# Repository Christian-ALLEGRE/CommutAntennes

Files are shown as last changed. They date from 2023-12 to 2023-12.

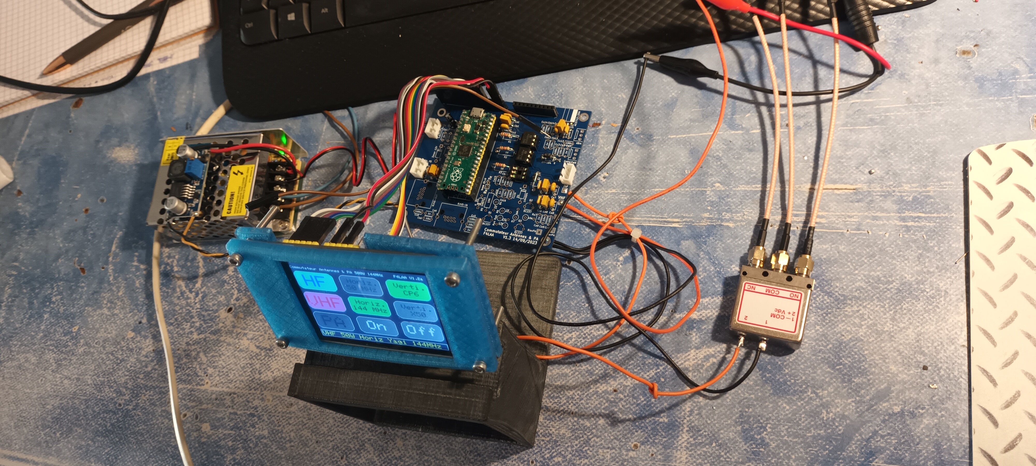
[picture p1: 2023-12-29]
images/20230930_181311.jpg

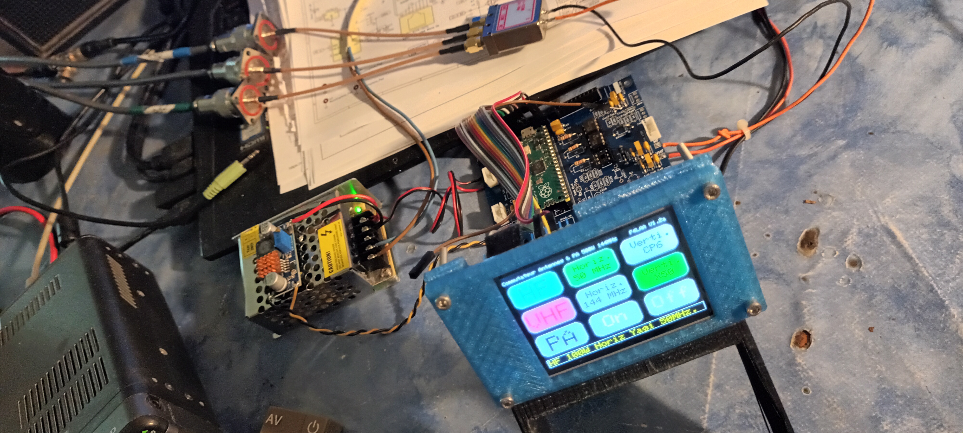
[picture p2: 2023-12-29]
images/20230930_235537.jpg

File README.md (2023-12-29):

# CommutAntennes
Antennas switcher using RPIPico and TFT 2"8 TouchScreen

V1.2 : 
  - The TFT 2"8 TouchScreen uses parallel 8 bits communication with RpiPico
  - PCB was manufactured by JLCPcb using Kicad/Ampli144MHz.zip (2023/09/14)
  - RpiPico Program V1.2 UI was design to manage :
    - The antenna switcher : 2 coax relay (HF and VHF)
    - A futur 144MHz 500W Power amplifier (not yet build at this time)
  
Updated on 29/12/2023 : 
  - The source code is now compatible with PlatformIO
    - CommutAntenneRpiPico-V1.2a.ino becomes src/main.cpp
    - The requested libraries were put in lib directory
    - a few lines where commented in GFX_Library_for_Arduino and TouchScreenOnRpPico
      to allow those libraries to compile (search for// F4LAA comment to find them)

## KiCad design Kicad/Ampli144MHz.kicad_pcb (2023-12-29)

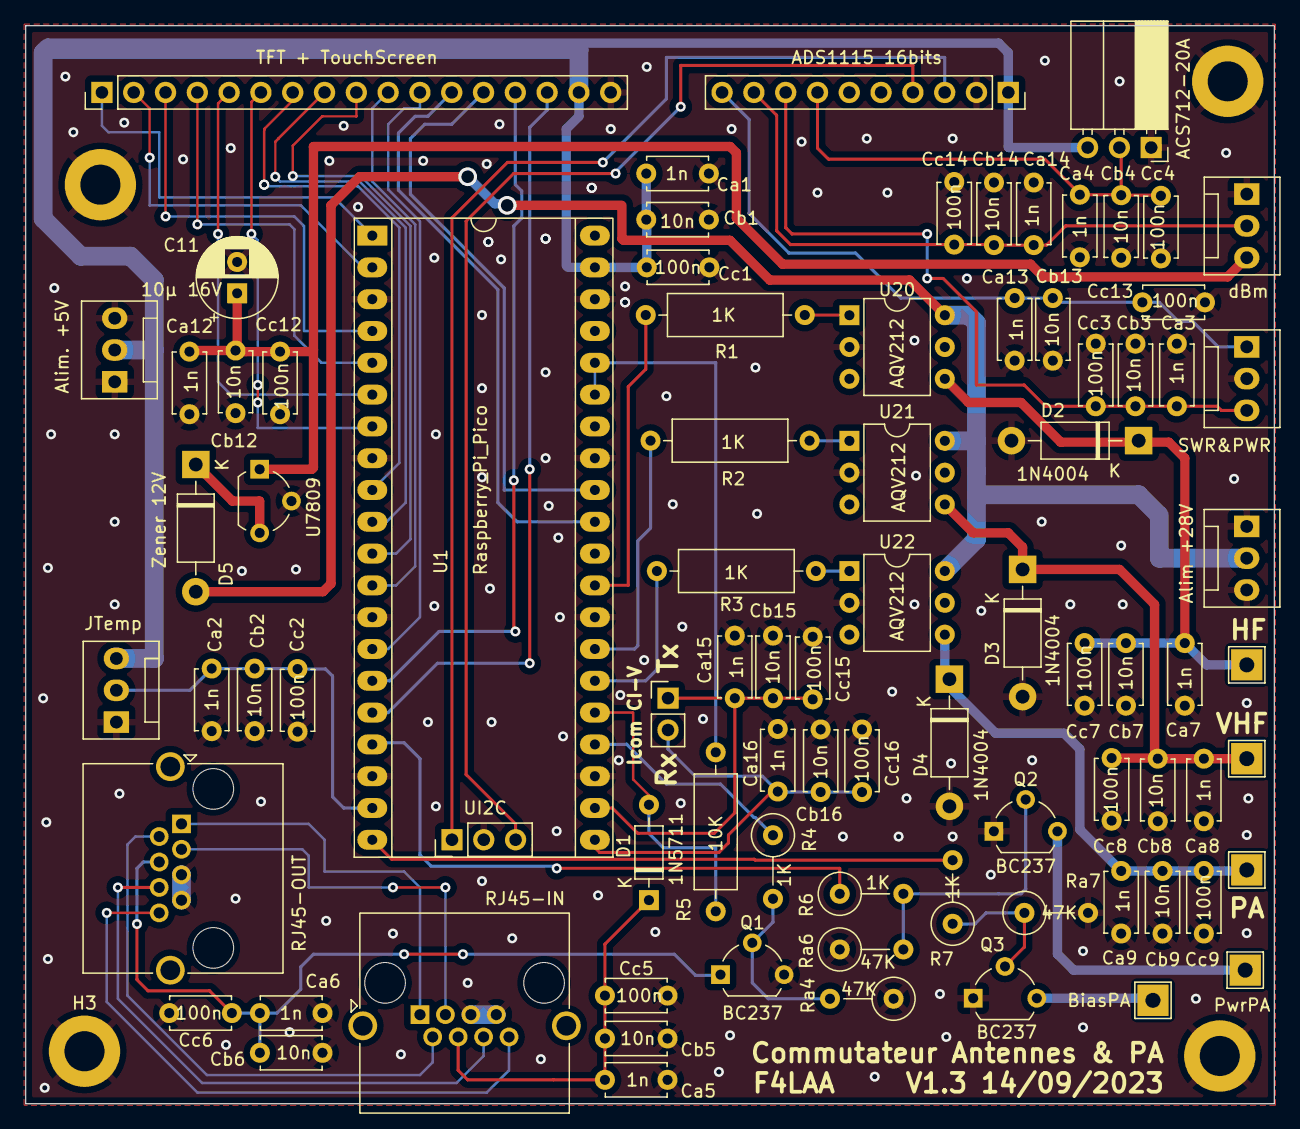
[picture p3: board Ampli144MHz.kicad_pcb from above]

Board: 2 copper layers, 99.7 x 86.1 mm, 87 parts (0 on the bottom side), 37 nets.

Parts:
Alim +28V: Alim28V; FanPinHeader_1x03_P2.54mm_Vertical
C11: 10µ 16V; CP_Radial_D6.3mm_P2.50mm
CK1: RELAY_K1; TestPoint_THTPad_2.5x2.5mm_Drill1.2mm
CK2: RELAY_K2; TestPoint_THTPad_2.5x2.5mm_Drill1.2mm
CK3: RELAY_K3; TestPoint_THTPad_2.5x2.5mm_Drill1.2mm
CK220V: Alim 48V PA; TestPoint_THTPad_2.5x2.5mm_Drill1.2mm
CKBias1: BiasPA; TestPoint_THTPad_2.5x2.5mm_Drill1.2mm
Ca1, Ca2, Ca3, Ca4, Ca5, Ca6, Ca7, Ca8, Ca9, Ca12, Ca13, Ca14, Ca15, Ca16: 1n; C_Disc_D4.7mm_W2.5mm_P5.00mm
Cb1, Cb2, Cb3, Cb4, Cb5, Cb6, Cb7, Cb8, Cb9, Cb12, Cb13, Cb14, Cb15, Cb16: 10n; C_Disc_D4.7mm_W2.5mm_P5.00mm
Cc1, Cc2, Cc3, Cc4, Cc5, Cc6, Cc7, Cc8, Cc9, Cc12, Cc13, Cc14, Cc15, Cc16: 100n; C_Disc_D4.7mm_W2.5mm_P5.00mm
D1: 1N5711; D_DO-35_SOD27_P7.62mm_Horizontal
D2, D3, D4: 1N4004; D_DO-41_SOD81_P10.16mm_Horizontal
D5: Zener 12V; D_DO-41_SOD81_P10.16mm_Horizontal
H1, H2, H3, H4: MountingHole_Pad; MountingHole_3.2mm_M3_ISO7380_Pad
J5: Alim. +5V; FanPinHeader_1x03_P2.54mm_Vertical
JADC16bits: ADS1115 16bits; PinSocket_1x10_P2.54mm_Vertical
JAmp: ACS712-20A; PinSocket_1x03_P2.54mm_Horizontal
JCIV1: Icom CI-V; PinHeader_1x02_P2.54mm_Vertical
JS+P: SWR&PWR; FanPinHeader_1x03_P2.54mm_Vertical
JTFT+Touch: TFT + TouchScreen; PinHeader_1x17_P2.54mm_Vertical
JTemp: Temp; FanPinHeader_1x03_P2.54mm_Vertical
JdBm: dBm; FanPinHeader_1x03_P2.54mm_Vertical
Q1, Q2, Q3: BC237; TO-92L_Wide
R1, R2, R3: 1K; R_Axial_DIN0309_L9.0mm_D3.2mm_P12.70mm_Horizontal
R4, R6, R7: 1K; R_Axial_DIN0309_L9.0mm_D3.2mm_P5.08mm_Vertical
R5: 10K; R_Axial_DIN0309_L9.0mm_D3.2mm_P12.70mm_Horizontal
RJ45-IN, RJ45-OUT: RJ45_Amphenol_RJHSE5380
Ra4, Ra6, Ra7: 47K; R_Axial_DIN0309_L9.0mm_D3.2mm_P5.08mm_Vertical
U1: Raspberry_Pi_Pico; DIP-40_0.700in_Socket_LongPads
U20, U21, U22: AQV212; DIP-6_W7.62mm
U7809: LM78L09; TO-92L_Wide
UI2C: I2C; PinHeader_1x03_P2.54mm_Vertical

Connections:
+3.3V: R5.2, U1.35, U1.36
+5V: Ca1.2, Cb1.1, Cc1.2, J5.2, JADC16bits.1, JAmp.3, JTFT+Touch.16, JTemp.3, U1.39
+9V: C11.1, Ca12.1, Cb12.1, Cc12.1, JdBm.3, U7809.1 (VO)
+16V: D5.1 (K), U7809.3 (VI)
+28V: Alim +28V.2, U20.6, U21.6, U22.6
ADC0: JTFT+Touch.12, U1.31
ADC1: JTFT+Touch.13, U1.32
Amp: Ca4.1, Cb4.1, Cc4.1, JADC16bits.7, JAmp.2
BiasPAOff: R7.2, U1.20
CBiasPA: CKBias1.1, Q3.3 (E)
CK1: CK1.1, Ca7.1, Cb7.2, Cc7.2, D2.1 (K), U20.4
CK2: CK2.1, Ca8.1, Cb8.1, Cc8.2, D3.1 (K), U21.4
CK3: CK3.1, Ca9.2, Cb9.2, Cc9.2, D4.1 (K), U22.4
CK220V: CK220V.1, Q2.3 (E)
CPAOnOff: R6.1, U1.17
CPTTOut: Q1.2 (B), R4.1, R4.2, U1.24
GND: Alim +28V.1, Alim +28V.3, C11.2, Ca1.1, Ca2.2, Ca3.2, Ca4.2, Ca5.2, Ca6.2, Ca7.2, Ca8.2, Ca9.1, Ca12.2, Ca13.1, Ca14.2, Ca15.2, Ca16.2, Cb1.2, Cb2.1, Cb3.2, Cb4.2, Cb5.2, Cb6.2, Cb7.1, Cb8.2, Cb9.1, Cb12.2, Cb13.1, Cb14.2, Cb15.2, Cb16.2, Cc1.1, Cc2.1, Cc3.2, Cc4.2, Cc5.2, Cc6.2, Cc7.1, Cc8.1, Cc9.1, Cc12.2, Cc13.2, Cc14.2, Cc15.2, Cc16.2, D2.2 (A), D3.2 (A), D4.2 (A), H1.1, H2.1, H3.1, H4.1, J5.1, J5.3, JADC16bits.2, JAmp.1, JS+P.2, JTFT+Touch.17, JTemp.1, JdBm.1, Q1.3 (E), Q2.1 (C), Q3.1 (C), RJ45-IN.5, RJ45-IN.7, RJ45-OUT.5, RJ45-OUT.7, Ra4.1, Ra6.1, Ra7.2, U1.3, U1.8, U1.13, U1.18, U1.23, U1.28, U1.33, U1.38, U20.2, U21.2, U22.2, U7809.2 (GND), UI2C.2
unnamed: D1.2 (A), R5.1
unnamed: Q2.2 (B), R6.2, Ra6.2
unnamed: R1.1, U1.29
unnamed: R1.2, U20.1
unnamed: R2.1, U1.27
unnamed: R2.2, U21.1
unnamed: R3.1, U1.26
unnamed: R3.2, U22.1
PTT In: Ca5.1, Cb5.1, Cc5.1, D1.1 (K), RJ45-IN.4, U1.25
PTTOut: Ca6.1, Cb6.1, Cc6.1, Q1.1 (C), RJ45-OUT.4
PWR: Ca13.2, Cb13.2, Cc13.1, JADC16bits.10, JS+P.1
RX: Ca16.1, Cb16.1, Cc16.1, JCIV1.2, U1.21
SCL: JADC16bits.3, UI2C.1
SDA: JADC16bits.4, UI2C.3
SWR: Ca3.1, Cb3.1, Cc3.1, JADC16bits.8, JS+P.3
TX: Ca15.1, Cb15.1, Cc15.1, JCIV1.1, U1.22
T°: Ca2.1, Cb2.2, Cc2.2, JTemp.2, U1.19
XP: JTFT+Touch.14, U1.15
YM: JTFT+Touch.15, U1.16
dBm: Ca14.1, Cb14.1, Cc14.1, JADC16bits.9, JdBm.2

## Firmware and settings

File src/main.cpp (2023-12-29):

// CommutAntenneRpiPico.ino
#define VERSION "V1.2a"
//
// Programme : Commutateur d'Antennes + PA VHF 500W
// Conçu par : F4LAA 
// Version   : V2.0 (15/09/2023)
//
// Programme inspiré de : 
//   Contrôleur de commutateur Coaxial 8:1 Ameritron (ou similaire), Version 1.
//   Utilise un Raspberry Pi Pico. Développé sous Arduino IDE.
//   Électro-Bidouilleur, Juin 2023. https://www.youtube.com/Électro-Bidouilleur
//   Licence de droits: Attribution 4.0 International (CC BY 4.0)  Lisez https://creativecommons.org/licenses/by/4.0/deed.fr
//
// =========================================================================================================================
// V1.0 (14/09/2023)
//
// TFTArduino : Ecran Elegoo 320 x 240 couleur + TouchScreen
//   Programme Arduino gérant l'affichage LCD du commutateur (boutons Commut H/V en HF et VHF, PA Enable/Disable, PA On/Off)
//   Dérivé du programme exemple Elegoo, il se trouve sur ACSOFTDVLP 
//   dans E:\ACSoft\DVLP\arduino-0022\ACSoft\Afficheurs\TFT\TFTArduino
//   Utilise une version modifiée de la librairie EleGoo_GFX (.cpp, .h) 
//     fonctions containsV() et containsH() (au lieu de contains() dans la librairie d'origine)
//
// =========================================================================================================================
// V2.0 (14/09/2023)
//
// Portage Arduino vers Raspeberry Pico
//   CommutAntenneRpiPico.ino
//   ==> Ce programme est la version Rpi Pico
//
// RpiPico+TFT Elegoo et Librairie GFX Library for Arduino V1.3.7 par "Moon On Our Nation...""
// https://github.com/moononournation/Arduino_GFX
// Trouvé par : https://www.instructables.com/ArduinoGFX/
//
// Adaptation F4LAA : 
//    Arduino_RPiPicoPAR8.h, .c :
//     Ajout de la méthode int32_t Arduino_RPiPicoPAR8::digitalPinToBitMask(int32_t pin) 
//     #define digitalPinToBitMask(pin)    (1UL << (pin))
//
//   Adaptation Arduino_GFX.h, .c :
//     Ajout classe Arduino_GFX_Button (repris de Elegoo_GFX_Button)
//
//   Adaptation Arduino_GFX_Library.h :
//     Mise en comentaire des databus/xxxx inutilisés 
//       Arduino_HWSPI, Arduino_RPiPicoPAR16, Arduino_RPiPicoSPI,  
//
// La define TARGET_RP2040 est active à la compilatiopn sur RpiPico.
// 
// =========================================================================================================================
//#include <EEPROM.h>

// Based on ELEGOO TouhScreen
#include <TouchScreenOnRpiPico.h> // by F4LAA

#define XP 0   // GPIO0 (Sur Arduino, c'était 8 = D0) can be a digital pin
#define YM 1   // GPIO1 (Sur Arduino, c'était 9 = D1) can be a digital pin
#define YP 26  // GPIO26 = ADC0 (Sur Arduino, c'était A3)  // must be an analog pin, use "An" notation!
#define XM 27  // GPIO27 = ADC1 (Sur Arduino, c'était A2)  // must be an analog pin, use "An" notation!

TouchScreen ts = TouchScreen(XP, YP, XM, YM, 300);
#define MINPRESSURE 75
#define MAXPRESSURE 300

// Touch For New ILI9341 TP / ADC RpiPico
// ATTENTION X, Y Ecran = Y, X TouchPad (à cause de la rotation de 270° non prise en compte par le TP)
//
// Pour le Y de l'écran (qui utilise le X du touchPad)
#define TS_MINX 786
#define TS_MAXX 3426

// Pour le X de l'écran (qui utilise le Y du touchPad)
#define TS_MINY 587 
#define TS_MAXY 3413

int xmin = 32000;
int xmax = 0;
int ymin = 32000;
int ymax = 0;

// TFT LCD connecté en // 8 bits (D0 ... D7 sur GPIO0 ... GPIO7)
// https://www.instructables.com/ArduinoGFX/
#include <Arduino_GFX_Library.h>

// Voici les connexions sur un Rasprerry Pi Pico. Les numéros indiqués correspondent aux appellations GPxx du brochage.
#define LCD_RD 8 // GPIO8 (Sur Arduino, c'était A1) // LCD Write goes to Analog 1
#define LCD_WR 9 // GPIO9 (Sur Arduino, c'était A0) // LCD Read goes to Analog 0
#define LCD_RESET 10 // GPIO10 (Sur Arduino, c'était A4) // Can alternately just connect to Arduino's reset pin
#define LCD_CS 26 // GPIO26_ADC0 (Sur Arduino, c'était A3, Must be Analog) // Chip Select goes to Analog 3
#define LCD_CD 27 // GPIO27_ADC1 (Sur Arduino, c'était A2 // Command/Data goes to Analog 2

//Elegoo_TFTLCD tft(LCD_CS, LCD_CD, LCD_WR, LCD_RD, LCD_RESET);
// Replaced by :
// Display D0-D7 connect to GPIO 0-7.
Arduino_DataBus *bus = new Arduino_RPiPicoPAR8(LCD_CD, LCD_CS, LCD_WR, LCD_RD); 
// More data bus class: https://github.com/moononournation/Arduino_GFX/wiki/Data-Bus-Class 

Arduino_GFX *tft = new Arduino_ILI9341(bus, LCD_RESET, 0 , false );
// More display class: https://github.com/moononournation/Arduino_GFX/wiki/Display-Class

// Color definitions
#define ILI9341_BLACK       0x0000      /*   0,   0,   0 */
#define ILI9341_NAVY        0x000F      /*   0,   0, 128 */
#define ILI9341_DARKGREEN   0x03E0      /*   0, 128,   0 */
#define ILI9341_DARKCYAN    0x03EF      /*   0, 128, 128 */
#define ILI9341_MAROON      0x7800      /* 128,   0,   0 */
#define ILI9341_PURPLE      0x780F      /* 128,   0, 128 */
#define ILI9341_OLIVE       0x7BE0      /* 128, 128,   0 */
#define ILI9341_LIGHTGREY   0xC618      /* 192, 192, 192 */
#define ILI9341_DARKGREY    0x7BEF      /* 128, 128, 128 */
#define ILI9341_BLUE        0x001F      /*   0,   0, 255 */
#define ILI9341_GREEN       0x07E0      /*   0, 255,   0 */
#define ILI9341_CYAN        0x07FF      /*   0, 255, 255 */
#define ILI9341_RED         0xF800      /* 255,   0,   0 */
#define ILI9341_MAGENTA     0xF81F      /* 255,   0, 255 */
#define ILI9341_YELLOW      0xFFE0      /* 255, 255,   0 */
#define ILI9341_WHITE       0xFFFF      /* 255, 255, 255 */
#define ILI9341_ORANGE      0xFD20      /* 255, 165,   0 */
#define ILI9341_GREENYELLOW 0xAFE5      /* 173, 255,  47 */
#define ILI9341_PINK        0xF81F

/******************* UI details */
#define BUTTON_X 48
#define BUTTON_Y 52
#define BUTTON_W 95 // 60
#define BUTTON_H 55 // 30
#define BUTTON_SPACING_X 15 // 20
#define BUTTON_SPACING_Y 10
#define BUTTON_TEXTSIZE 3

// We have a setHeader line for like, is FONA working
#define posHeader_X 0
#define posHeader_Y 10

// text box where numbers go
#define TEXT_X 1
#define TEXT_Y 218 // 10
#define TEXT_W 318 // 220
#define TEXT_H 20
#define TEXT_TSIZE 2
#define TEXT_TCOLOR ILI9341_YELLOW

#define RelaiAlimPA 11  // GPIO11
#define DTemp 14        // GPIO14
#define PttOut 18       // GPIO18
#define PttIn 19        // GPIO19
#define RelaiPA 20      // GPIO20
#define RelaiVHF 21     // GPIO21
#define RelaiHF 22      // GPIO22

String msg = "";

// #include <Arduino_GFX_Button.h>
Arduino_GFX_Button buttons[9];

/* create 15 buttons, in classic candybar phone style */
char buttonlabels[9][15] = {"HF", " Horiz.50 MHz", " Verti. CP6", "VHF", " Horiz.144 MHz", " Verti. X50", "PA", "On", "Off" };
uint16_t buttoncolors[9] = {ILI9341_CYAN, ILI9341_LIGHTGREY, ILI9341_GREEN,
                            ILI9341_PINK, ILI9341_LIGHTGREY, ILI9341_GREEN, 
                             ILI9341_LIGHTGREY, ILI9341_LIGHTGREY, ILI9341_LIGHTGREY };
uint16_t buttonTextcolors[9] = {ILI9341_BLUE, ILI9341_BLACK, ILI9341_BLACK,
                                ILI9341_RED, ILI9341_BLACK, ILI9341_BLACK,
                                ILI9341_BLACK, ILI9341_WHITE, ILI9341_WHITE };
uint16_t buttonTextsizes[9] = { 5, 2, 2,
                                5, 2, 2,
                                5, 4, 4 };
                             
Arduino_GFX_Button mButtons[9];
char mButtonlabels[9][6] = {"Exit", "?", "?", "?", "?", "?", "?", "?", "?" };
uint16_t mButtoncolors[9] = {ILI9341_OLIVE, ILI9341_LIGHTGREY, ILI9341_LIGHTGREY,
                            ILI9341_LIGHTGREY, ILI9341_LIGHTGREY, ILI9341_LIGHTGREY, 
                             ILI9341_LIGHTGREY, ILI9341_LIGHTGREY, ILI9341_LIGHTGREY };
uint16_t mButtonTextcolors[9] = {ILI9341_WHITE, ILI9341_WHITE, ILI9341_WHITE,
                                ILI9341_WHITE, ILI9341_WHITE, ILI9341_WHITE,
                                ILI9341_WHITE, ILI9341_WHITE, ILI9341_WHITE };

void setHeader(String msg) {
  tft->fillRect(posHeader_X, posHeader_Y, 240, 8, ILI9341_BLACK);
  tft->setCursor(posHeader_X, posHeader_Y);
  tft->setTextColor(ILI9341_WHITE);
  tft->setTextSize(1);
  tft->print(msg);
}

void setMessage(String s) {
  //Serial.println(s);
  tft->setCursor(TEXT_X + 3, TEXT_Y+3);
  tft->setTextColor(TEXT_TCOLOR, ILI9341_BLACK);
  tft->fillRect(TEXT_X + 1, TEXT_Y + 1, TEXT_W - 2, TEXT_H - 2, ILI9341_BLACK); 
  tft->setTextSize(TEXT_TSIZE);
  tft->print(s);
}

/* */
enum eState {
  RUN, 
  CONFIG
  };
eState curState;
/* */

void clearButtons()
{
  tft->fillRect(0, BUTTON_Y - (BUTTON_H / 2), 320, BUTTON_Y - (BUTTON_H / 2) + 3 * (BUTTON_H + BUTTON_SPACING_Y), BLACK);
  // create 'text field'
  tft->drawRect(TEXT_X, TEXT_Y, TEXT_W, TEXT_H, ILI9341_WHITE); 
}

void drawRunButtons()
{
  for (uint8_t row=0; row<3; row++) {
    for (uint8_t col=0; col<3; col++) {
      buttons[col + row*3].drawButton();
    }
  }
}

void drawConfigButtons()
{
  for (uint8_t row=0; row<3; row++) {
    for (uint8_t col=0; col<3; col++) {
      mButtons[col + row*3].drawButton();
    }
  }
}
void updateUI()
{
  clearButtons();

  switch (curState) {
    case RUN:
      drawRunButtons();
      break;
    case CONFIG:
      drawConfigButtons();
      break;
  }
}

void setup(void) {
  Serial.begin(9600);
  Serial.println(String("Commutateur d'Antennes et PA / Rpi Pico ") + VERSION);

  // Gestion du Commutateur d'antenne
  pinMode(RelaiHF, OUTPUT);                              
  digitalWrite(RelaiHF, LOW);                            // Les broches de relais au niveau bas pour commencer
  pinMode(RelaiVHF, OUTPUT);                              
  digitalWrite(RelaiVHF, LOW);                           // Les broches de relais au niveau bas pour commencer

  // Gestion du PA
  pinMode(RelaiAlimPA, OUTPUT);                              
  digitalWrite(RelaiAlimPA, LOW);                        // Les broches de relais au niveau bas pour commencer
  pinMode(RelaiPA, OUTPUT);                              
  digitalWrite(RelaiPA, LOW);                            // Les broches de relais au niveau bas pour commencer
  pinMode(DTemp, INPUT);                                 // Capteur Numérique de température du radiateur du PA

  // Gestion du TX (Port CI-V sur un fil ==> UART0)
  pinMode(PttIn, INPUT);                                 // La broche PttIn initalisée en entrée
  pinMode(PttOut, OUTPUT);                               // La broche PttOut initalisée en sortie

  // ADC en 12 bits (default is 10)
  analogReadResolution(12);

  //EEPROM.begin(256);                                      // Démarrer l'instance d'accès EEPROM (émulation dans la Flash)
  //while (!Serial && (millis() <= 1000));                  // Une pause d'au moins 1 seconde

  // Init Display
  if (!tft->begin())
  {
    //Serial.println("tft->begin() failed!");
  }
  tft->setRotation(1); // 0 = 0°, 1 = 90°, 2 = 180°, 3 = 270° 
  tft->fillScreen(BLACK);
  
  // create buttons
  for (uint8_t row=0; row<3; row++) {
    for (uint8_t col=0; col<3; col++) {
      buttons[col + row*3].initButton(tft, BUTTON_X+col*(BUTTON_W+BUTTON_SPACING_X), 
                  BUTTON_Y+row*(BUTTON_H+BUTTON_SPACING_Y),    // x, y, w, h, outline, fill, text
                  BUTTON_W, BUTTON_H, ILI9341_WHITE, buttoncolors[col+row*3], buttonTextcolors[col+row*3],
                  buttonlabels[col + row*3], buttonTextsizes[col+row*3]); 
    }
  }

  // create Menu buttons
  for (uint8_t row=0; row<3; row++) {
    for (uint8_t col=0; col<3; col++) {
      mButtons[col + row*3].initButton(tft, BUTTON_X+col*(BUTTON_W+BUTTON_SPACING_X), 
                  BUTTON_Y+row*(BUTTON_H+BUTTON_SPACING_Y),    // x, y, w, h, outline, fill, text
                  BUTTON_W, BUTTON_H, ILI9341_WHITE, mButtoncolors[col+row*3], mButtonTextcolors[col+row*3],
                  mButtonlabels[col + row*3], BUTTON_TEXTSIZE); 
    }
  }
  
  clearButtons(); // Draw TextField
  drawRunButtons();
  setHeader(String("Commutateur Antennes & PA 500W 144MHz    F4LAA ") + VERSION);
  setMessage("Commutateur Ant+PA   F4LAA"); // 16 char max
  curState = RUN;
}

bool HorizHF = false;
bool HorizVHF = false;
bool sHorizVHF = false;
bool PAEnabled = false;
bool PAOn = false;

int cptPA = 0;
int cptPA2 = 0;

void setHFOn(bool on)
{
  if (on)
    digitalWrite(RelaiHF, HIGH);
  else
    digitalWrite(RelaiHF, LOW);
}

void setVHFOn(bool on)
{
  if (on)
    digitalWrite(RelaiVHF, HIGH);
  else
    digitalWrite(RelaiVHF, LOW);
}

void setAlimPAOn(bool on)
{
  if (on)
    digitalWrite(RelaiAlimPA, HIGH);
  else
    digitalWrite(RelaiAlimPA, LOW);
}

bool pttOut = false;
void setPttOut(bool on)
{
  if (on)
    digitalWrite(PttOut, HIGH);
  else
    digitalWrite(PttOut, LOW);
  pttOut = on;
}

void setPAOn(bool on)
{
  if (on)
    digitalWrite(RelaiPA, HIGH);
  else
    digitalWrite(RelaiPA, LOW);
}
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
void loop(void) {
  // Lecture du PTT et gestion des antennes "RX"
  if (pttActif != !digitalRead(PttIn))                            // Niveau bas actif sur la broche PTT_In?
    pttActif = !digitalRead(PttIn);                               // Oui, changer l'état de la variable PTT
  
  if (pttActif)        // Antenne ne permettant pas d'émettre (Tx)?
  { // PTT Enfoncé
    // On veut emmetre
    if (! pttOut)
    {
      // Il faut passer en émission
      if (PAOn)
      {
        // Séquenceur
        setPAOn(true);   // Commuter le relai transfer en émission
        delay(WAITRELAY);       // Pause séquenceur
        setPttOut(true); // Envoyer le PTT au TX (emission HF)
      }
      else
        setPttOut(true);
    }
  }
  else
  { // PTT Relaché
    // On veut arrêter d'emmetre
    if (pttOut)
    {
      // Il faut couper l'émission
      if (PAOn)
      {
        setPttOut(false); // On coupe la HF
        delay(WAITRELAY);        // Pause séquenceur
        setPAOn(false);   // Commuter le relai transfer en réception
      }
      else
        setPttOut(false); // On coupe la HF
    }
  }

  // Traitement des actions tactiles
  // Read TouchPad...
  TSPoint p = getTouchPoint();

  // go thru all the buttons, checking if they were pressed
  switch (curState) {
    case RUN:
      manageRun(p);

      if (PAOn)
      {
        // Faire bouger le BarGraph de Puissance
        cptPA2++;
        if (cptPA2 > 750)
        {
          cptPA2 = 0;        
          int val = (fSin[cptPA] * 320.0); 
          barGraph(val);
          cptPA++; 
          if (cptPA >= 10)
            cptPA = 0;
        }
      }
      break;

    case CONFIG:
      manageConfig(p);
      break;
  } // switch curState  

  // Gestion changement de fréquence sur le transceiver
  if (nouv_frequence_dispo)                                                 // Nouvelle fréquence disponible pour analyse?
  {
    // Affixcher la fréquence du TX

    // Traité
    nouv_frequence_dispo = false;                                       // Annuler le fanion de nouvelle fréquence disponible
  }
}

//************************************************************************************************************************
// 2ème coeur...
//************************************************************************************************************************

// Fonction d'initialisation du deuxième coeur du Pico, style Arduino, exécutée une seule fois à la mise sous tension
void setup1()
{
  Serial1.begin(9600);                                    // Port série UART0 / Serial1 connecté au transceiver (protocole CI-V)

  // Envoi d'une requête initiale de fréquence. Si pas de réponse obtenue, les antennes en EEPROM seront applicables.
  const byte tx_data[] = {0xFE, 0xFE, 0x94, 0xE0, 0x03, 0xFD}; // La syntaxe du message de requête de fréquence
  Serial1.write(tx_data, sizeof(tx_data));                     // Envoi du message
}

unsigned int caract;                                            // Caractère reçu sur le port CI-V
unsigned int rx_data[15];                                       // Chaîne de caractères reçus sur le port CI-V
unsigned int byte_pos = 0;                                      // Position du caractère lu sur la chaîne de caractères

// Cette boucle du deuxième coeur monitore la fréquence du transceiver et signale au premier coeur un changement de fréquence
void loop1()
{
  // Gestion des messages CI-V de fréquence courante du transceiver. Signale lorsque les MHz de la fréquence changent
  if (Serial1.available())                      // Octet(s) disponible en tampon du port CI-V?
  {
    rx_data[byte_pos] = Serial1.read();         // Oui, le(s) lire
    //    Serial.println(rx_data[byte_pos]);    // Afficher les octets reçus pour fins de déboggage
    if (rx_data[byte_pos] == 0xFD)              // Octet de fin de message reçu?
    {
      if (( rx_data[0] == 0xfe          // Message de fréquence automatiquement envoyé par le transceiver?...
            && rx_data[1] == 0xfe
            && rx_data[2] == 0x00
            && rx_data[3] == 0x94
            && rx_data[4] == 0x00)
          || ( rx_data[0] == 0xfe         // ...ou message de fréquence suite à une requête manuelle (mise sous tension)?
               && rx_data[1] == 0xfe
               && rx_data[2] == 0xE0
               && rx_data[3] == 0x94
               && rx_data[4] == 0x03))
      {
        frequence = ((rx_data[8] & 0x0F) + (((rx_data[8] >> 4) & 0x0F) * 10));    // Oui, extraire la fréquence (en MHz arrondis) du message
        if (frequence != old_frequence)                                           // Vérifier si c'est une nouvelle fréquence en MHz
        { 
          old_frequence = frequence;                                              // Oui, sauvegarder la nouvelle fréquence comme ancienne fréquence
          nouv_frequence_dispo = true;                                            // Aviser qu'une nouvelle fréquence est disponible
        }
      }
      byte_pos = 0;                                                               // Ré-initialiser le pointeur de position de la chaîne d'octets reçue
    }
    else byte_pos++;                                                              // Caractère de fin de message non reçu: Incrémenter le pointeur de position de la chaîne d'octets reçue
  }
}

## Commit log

2023-12-29 new file: .gitignore new file: .vscode/extensions.json new file: Fao/Ampli144MHz-B_Cu.gbr new file: Fao/Ampli144MHz-B_Mask.gbr new file: Fao/Ampli144MHz-B_Paste.gbr new file: Fao/Ampli144MHz-B_Silksc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
    [Ampli144MHz-B_Cu.gbr, Ampli144MHz-B_Mask.gbr, Ampli144MHz-B_Paste.gbr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]
2023-12-29 new file: lib/GFX_Library_for_Arduino/README.md new file: lib/GFX_Library_for_Arduino/examples/ArduinoVNC/ArduinoVNC.ino new file: lib/GFX_Library_for_Arduino/examples/ArduinoVNC/VNC_GFX.h new file: 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
